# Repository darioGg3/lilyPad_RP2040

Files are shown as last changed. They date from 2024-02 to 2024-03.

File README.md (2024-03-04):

# lilyPad_RP2040
 lilyPad style board with an RP2040, it was design in KiCAD 8.0 .

 Characteristics:
 - Powering via USB C or Pins (3.3V - GND).
 - Programing via USB.
 - Debugging port available SWD.
 - 128Mb Flash memory.
 - 16 GPIOs, 3 of them ADC inputs.
 - Programable LED on GPIO13.
 
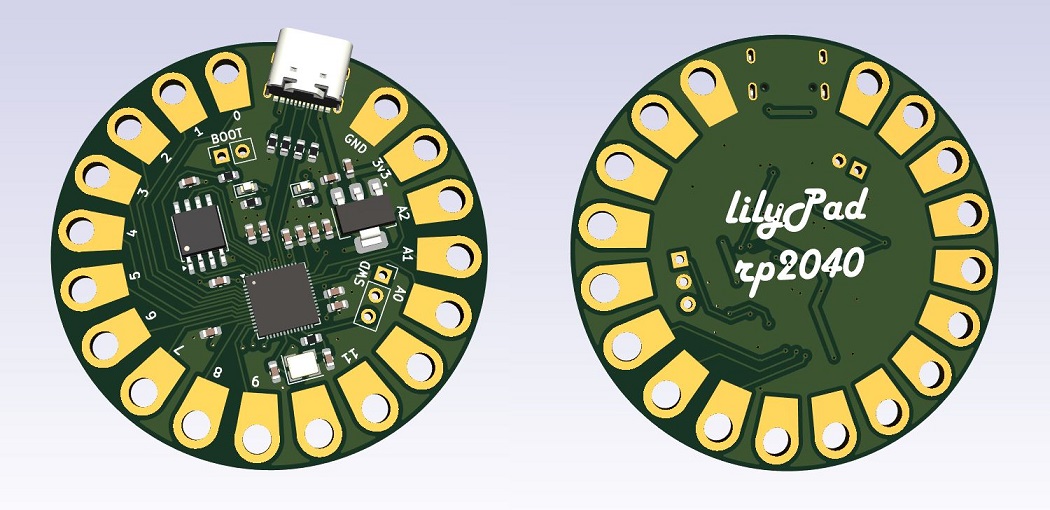
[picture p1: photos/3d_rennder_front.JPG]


<p align="center">
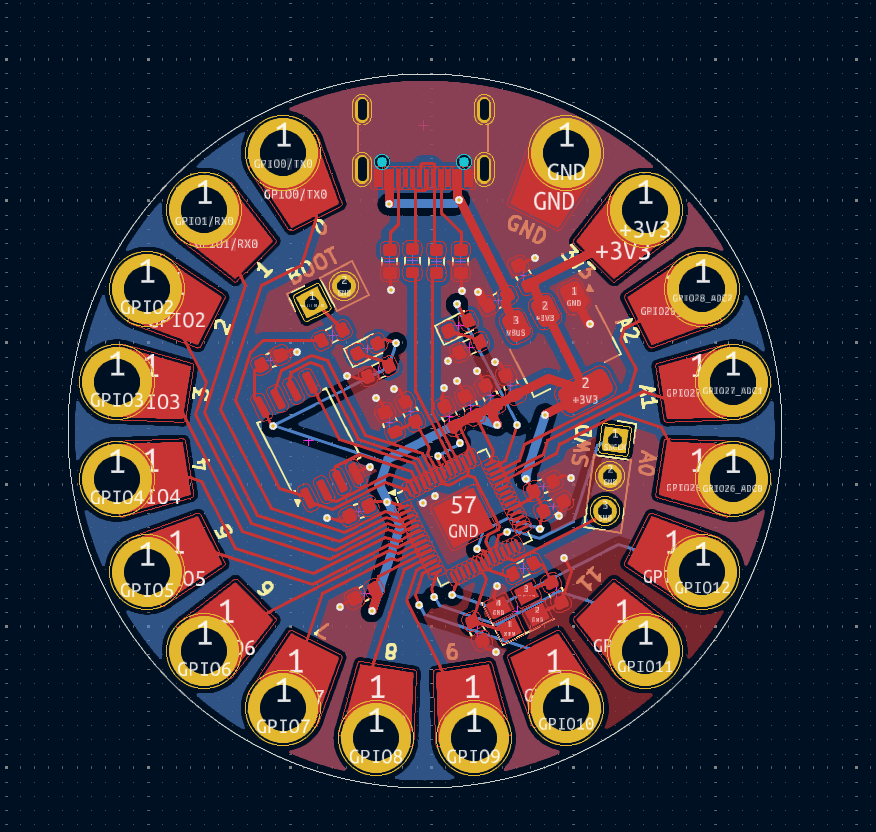
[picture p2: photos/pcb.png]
  
</p>

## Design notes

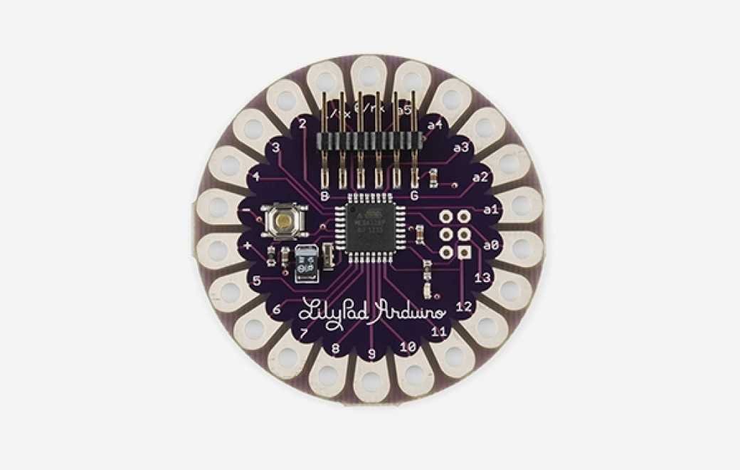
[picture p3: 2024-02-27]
lilypad_main.jpg

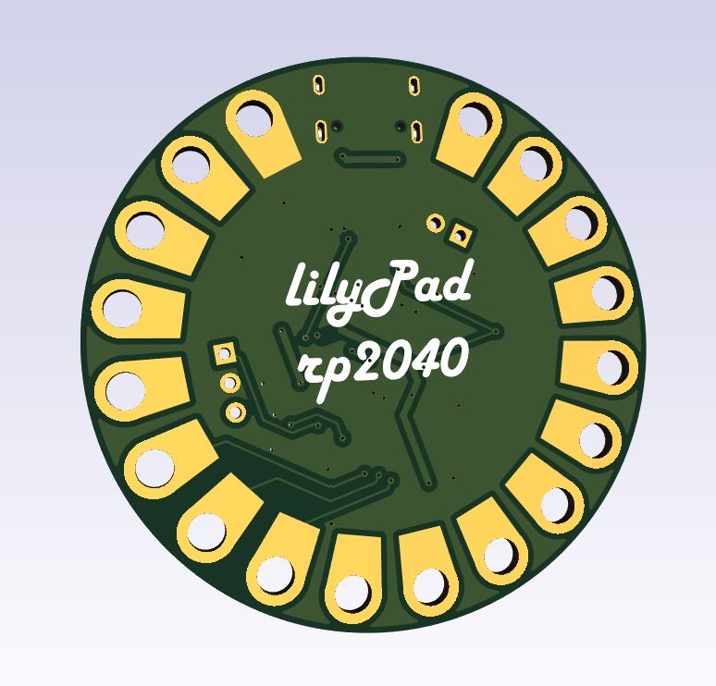
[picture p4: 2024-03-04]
photos/3d_rennder_back.JPG

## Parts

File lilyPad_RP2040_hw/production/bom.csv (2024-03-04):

Designator | Footprint | Quantity | Value | LCSC Part #
C1, C10, C11, C2, C3, C4, C5, C6, C7 | 0603 | 9 | 100nF
C12, C13 | 0603 | 2 | 22pF
C14, C15 | 0603 | 2 | 10uF
C8, C9 | 0603 | 2 | 1uF
D1, D2 | 0603 | 2 | LED
J2 | USB_C_Receptacle_G-Switch_GT-USB-7010ASV | 1 | USB_C_Receptacle_USB2.0_14P
R1, R2 | 0603 | 2 | 27R
R3, R4 | 0603 | 2 | 1k
R5, R6 | 0603 | 2 | 5.1k
R7, R8 | 0603 | 2 | 220
U1 | QFN-56-1EP_7x7mm_P0.4mm_EP3.2x3.2mm | 1 | RP2040
U2 | SOIC-8_5.23x5.23mm_P1.27mm | 1 | W25Q128JVS
U3 | SOT-223-3_TabPin2 | 1 | AMS1117-3.3
Y1 | Crystal_SMD_3225-4Pin_3.2x2.5mm | 1 | C9002

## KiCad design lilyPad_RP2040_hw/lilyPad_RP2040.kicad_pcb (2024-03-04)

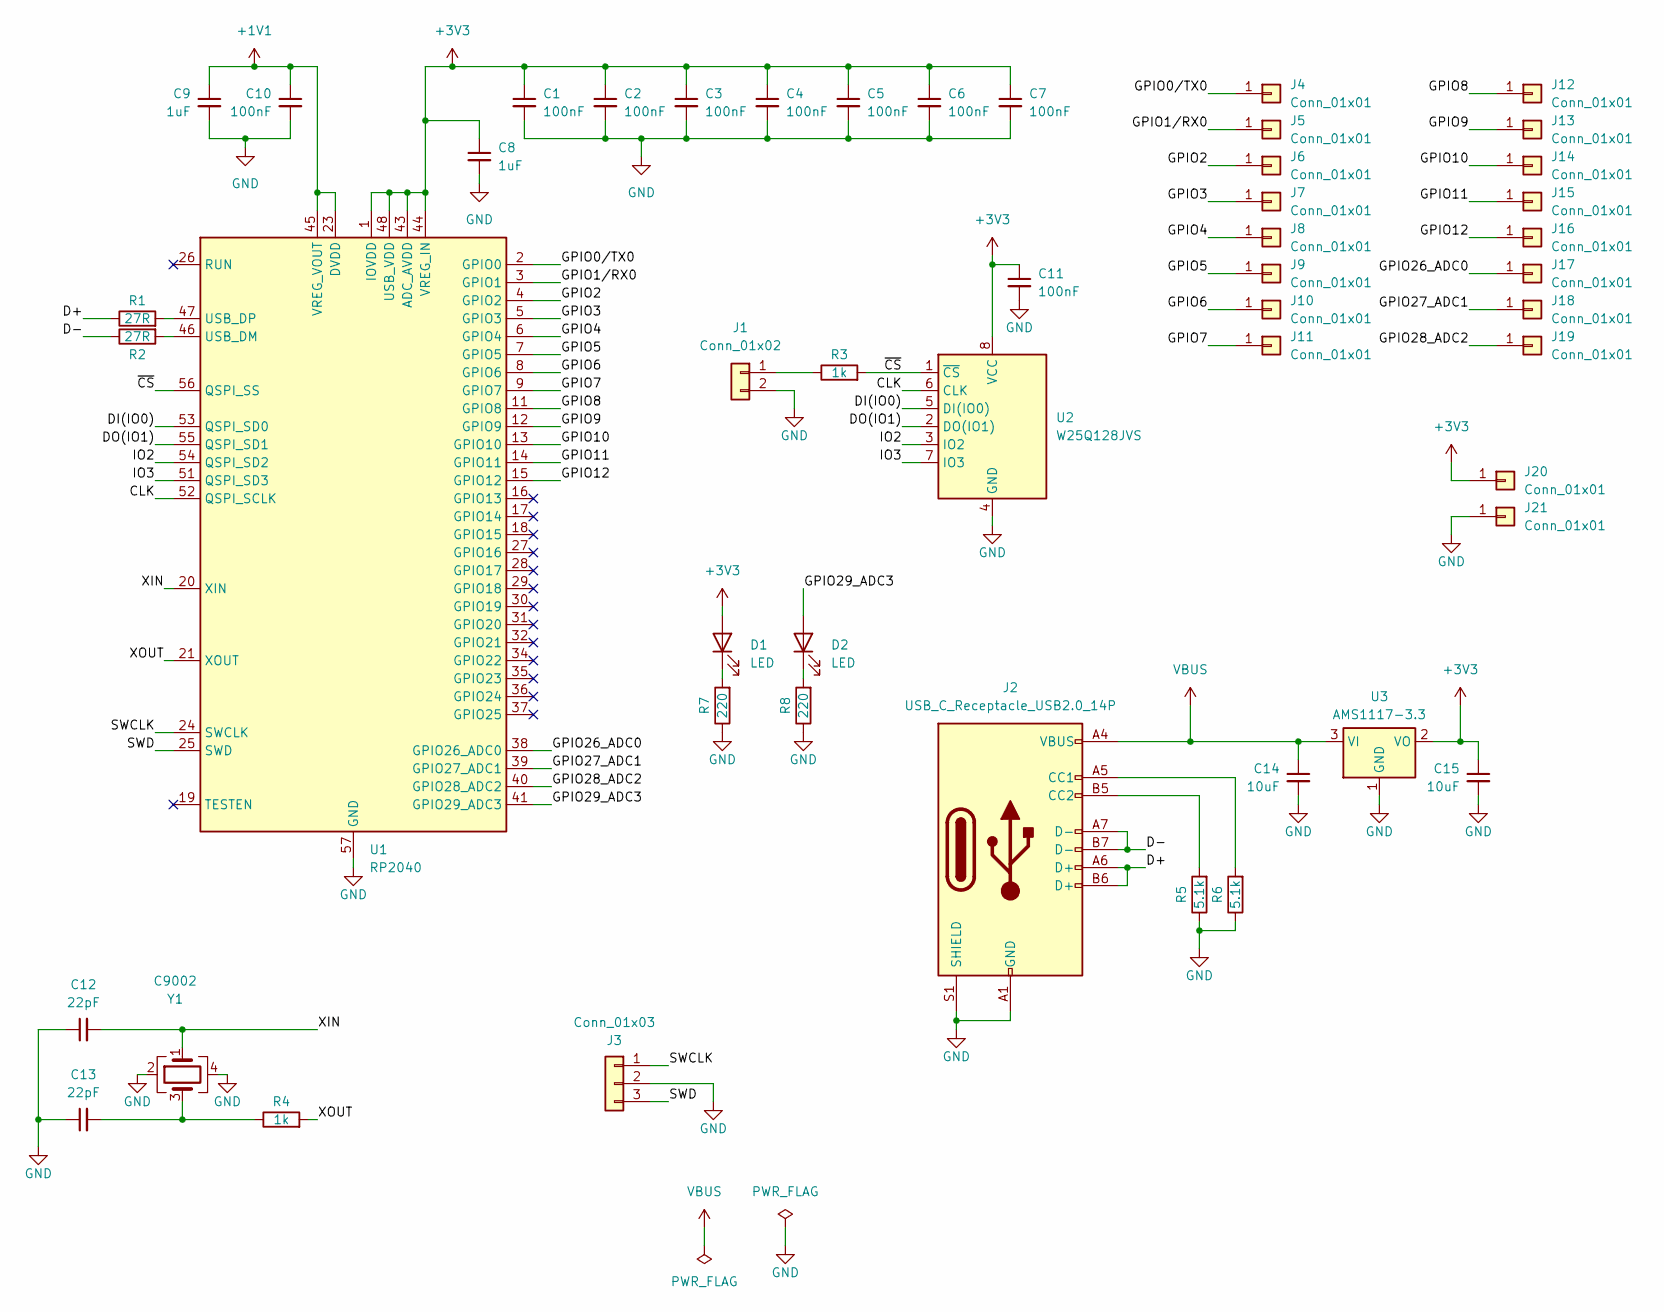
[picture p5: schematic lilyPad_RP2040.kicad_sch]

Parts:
C1, C2, C3, C4, C5, C6, C7, C10, C11: 100nF; C_0603_1608Metric
C8, C9: 1uF; C_0603_1608Metric
C12, C13: 22pF; C_0603_1608Metric
C14, C15: 10uF; C_0603_1608Metric
D1, D2: LED; LED_0603_1608Metric
J1: Conn_01x02; PinSocket_1x02_P2.54mm_Vertical
J2: USB_C_Receptacle_USB2.0_14P; USB_C_Receptacle_G-Switch_GT-USB-7010ASV
J3: Conn_01x03; PinSocket_1x03_P2.54mm_Vertical
J4, J5, J6, J7, J8, J9, J10, J11, J12, J13, J14, J15, J16, J17, J18, J19, J20, J21: Conn_01x01; LilyPad_Pad
R1, R2: 27R; R_0603_1608Metric
R3, R4: 1k; R_0603_1608Metric
R5, R6: 5.1k; R_0603_1608Metric
R7, R8: 220; R_0603_1608Metric
U1: RP2040; QFN-56-1EP_7x7mm_P0.4mm_EP3.2x3.2mm
U2: W25Q128JVS; SOIC-8_5.23x5.23mm_P1.27mm
U3: AMS1117-3.3; SOT-223-3_TabPin2
Y1: C9002; Crystal_SMD_3225-4Pin_3.2x2.5mm

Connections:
+1V1: C9.1, C10.1, U1.23 (DVDD), U1.45 (VREG_VOUT), U1.50 (DVDD)
+3V3: C1.1, C2.1, C3.1, C4.1, C5.1, C6.1, C7.1, C8.1, C11.1, C15.1, D1.2 (A), J20.1, U1.1 (IOVDD), U1.10 (IOVDD), U1.22 (IOVDD), U1.33 (IOVDD), U1.42 (IOVDD), U1.43 (ADC_AVDD), U1.44 (VREG_IN), U1.48 (USB_VDD), U1.49 (IOVDD), U2.8 (VCC), U3.2 (VO)
/CLK: U1.52 (QSPI_SCLK), U2.6 (CLK)
/D+: J2.A6 (D+), J2.B6 (D+), R1.1
/D-: J2.A7 (D-), J2.B7 (D-), R2.1
/DI(IO0): U1.53 (QSPI_SD0), U2.5 (DI(IO0))
/DO(IO1): U1.55 (QSPI_SD1), U2.2 (DO(IO1))
/GPIO0/TX0: J4.1, U1.2 (GPIO0)
/GPIO1/RX0: J5.1, U1.3 (GPIO1)
/GPIO2: J6.1, U1.4 (GPIO2)
/GPIO3: J7.1, U1.5 (GPIO3)
/GPIO4: J8.1, U1.6 (GPIO4)
/GPIO5: J9.1, U1.7 (GPIO5)
/GPIO6: J10.1, U1.8 (GPIO6)
/GPIO7: J11.1, U1.9 (GPIO7)
/GPIO8: J12.1, U1.11 (GPIO8)
/GPIO9: J13.1, U1.12 (GPIO9)
/GPIO10: J14.1, U1.13 (GPIO10)
/GPIO11: J15.1, U1.14 (GPIO11)
/GPIO12: J16.1, U1.15 (GPIO12)
/GPIO26_ADC0: J17.1, U1.38 (GPIO26_ADC0)
/GPIO27_ADC1: J18.1, U1.39 (GPIO27_ADC1)
/GPIO28_ADC2: J19.1, U1.40 (GPIO28_ADC2)
/GPIO29_ADC3: D2.2 (A), U1.41 (GPIO29_ADC3)
/IO2: U1.54 (QSPI_SD2), U2.3 (IO2)
/IO3: U1.51 (QSPI_SD3), U2.7 (IO3)
/SWCLK: J3.1, U1.24 (SWCLK)
/SWD: J3.3, U1.25 (SWD)
/XIN: C12.2, U1.20 (XIN), Y1.1
/XOUT: R4.2, U1.21 (XOUT)
/~CS: R3.2, U1.56 (QSPI_SS), U2.1 (~CS)
GND: C1.2, C2.2, C3.2, C4.2, C5.2, C6.2, C7.2, C8.2, C9.2, C10.2, C11.2, C12.1, C13.1, C14.2, C15.2, J1.2, J2.A1 (GND), J2.A12 (GND), J2.B1 (GND), J2.B12 (GND), J2.S1 (SHIELD), J3.2, J21.1, R5.1, R6.1, R7.1, R8.1, U1.57 (GND), U2.4 (GND), U3.1 (GND), Y1.2, Y1.4
unnamed: C13.2, R4.1, Y1.3
unnamed: D1.1 (K), R7.2
unnamed: D2.1 (K), R8.2
unnamed: J1.1, R3.1
unnamed: J2.A5 (CC1), R6.2
unnamed: J2.B5 (CC2), R5.2
unnamed: R2.2, U1.46 (USB_DM)
unnamed: R1.2, U1.47 (USB_DP)
VBUS: C14.1, J2.A4 (VBUS), J2.A9 (VBUS), J2.B4 (VBUS), J2.B9 (VBUS), U3.3 (VI)

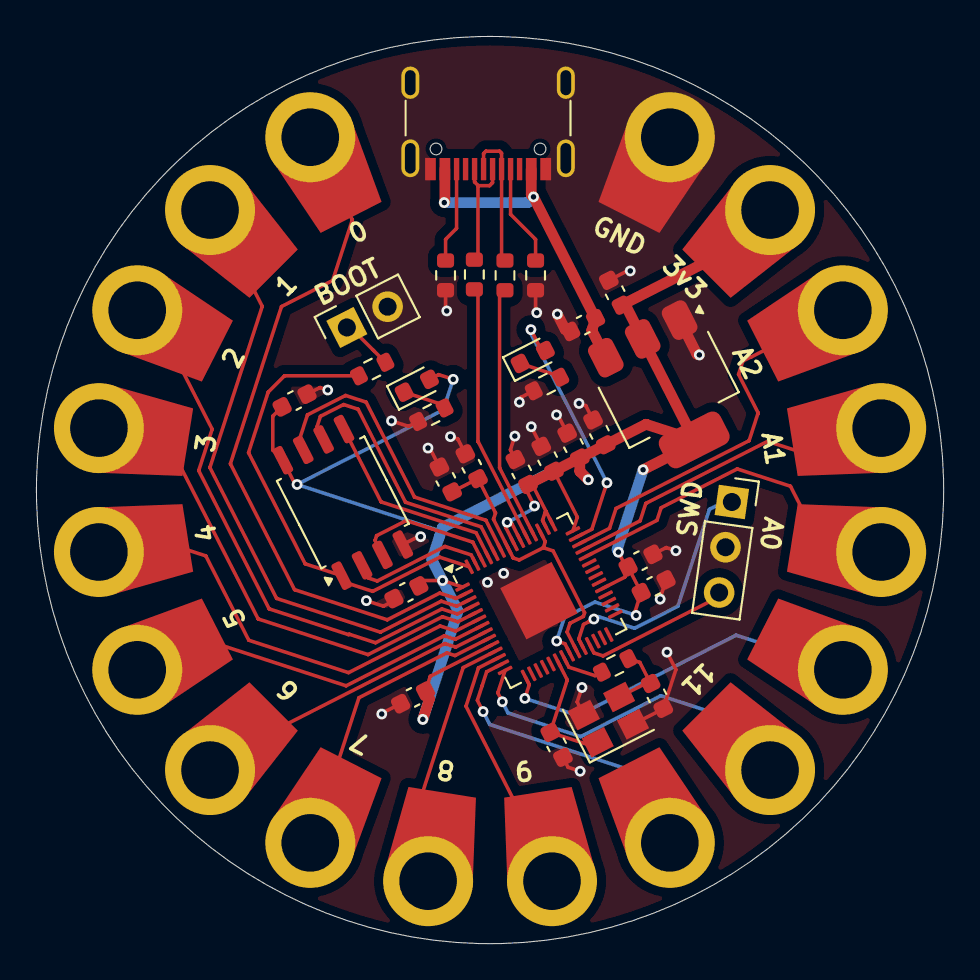
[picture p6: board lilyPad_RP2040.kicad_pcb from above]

Board: 2 copper layers, 50.4 x 50.4 mm, 50 parts (0 on the bottom side), 41 nets.
